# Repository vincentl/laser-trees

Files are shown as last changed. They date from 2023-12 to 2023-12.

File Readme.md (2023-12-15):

# Two Part Laser Cut Christmas Tree with 3D Printed Star

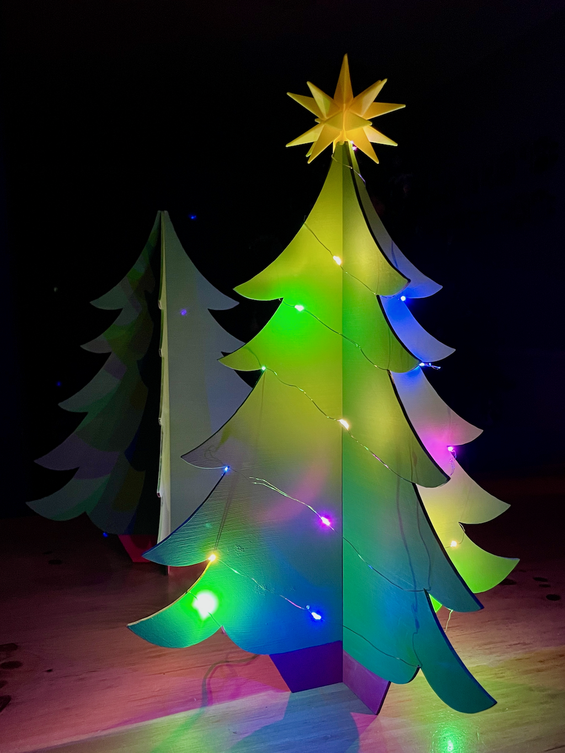
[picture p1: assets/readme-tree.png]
Image of two intersecting Christmas tree profiles that form a 3D tree


This project contains SVG outlines for laser cutting 2-part Christmas trees
from 3mm plywood and 3D printing stars for larger trees.

## SVG files for Laser Cutting Trees

The `trees` directory contains various SVG files that contains paths to cut two
Christmas tree silhouettes from 3mm plywood. The two parts interlock to form a 
self-supporting, 3D Christmas tree.
- `2-part-tree-50mm.svg`, `2-part-tree-75mm.svg`, and `2-part-tree-100mm.svg`, contain paths for both parts and the dimension indicates the height of the tree
- `2-part-tree-400mm-square-bottom.svg` and `2-part-tree-400mm-square-top.svg` each contain a path for one part that fits on a 400mm square plywood sheet that together produce a 445mm tall tree.
- `2-part-tree-template.svg` contains two paths that must be aligned and combined to form a tree of any desired height.
  - Scale the tree path to the desired height and lock the width to scale proportional to the height
  - Scale the rectangular cut path to **half** the desired height **independent** of the width
  - Adjust the width of the rectangular cut to match the material thickness plus a tolerance
  - Repeat the following steps twice to create the two different interlocking parts
    - Align the rectangle to top of the tree (and then the bottom for the other part)
    - Select both parts and combine with the "Difference" operator

## 3D Stars

The `stars` directory contains two 3D models for tree topper stars. Both models
have three types of parts:
- `core` is polyhedron center for that star and the other parts are glued to the core
- spikes that form the majority of the star
- `clip` is a truncated spike designed to clip onto the top of the tree. The clips are designed for 3mm plywood and are sized for a 445mm tall tree.

The parts are designed in [OpenSCAD](https://openscad.org/) language. OpenSCAD
renders 3D models and the rendered models for each part is also included in
this project for convenience.

### Stellated Dodecahedron Star

The [Great Stellated Dodecahedron](https://en.wikipedia.org/wiki/Great_stellated_dodecahedron)
looks like an icosahedron with 20 spikes. In this 3D model, one spike is 
modified to anchor the star to the tree.
- Print one `core` and one `clip`. Print these with some amount of infill for strength.
- Print 19 `spike` parts. These can be printed in "vase" mode with zero infill.
- Use glue appropriate for the 3D printing material and adhere each part to the core.

### Moravian Star

A [Moravian Star](https://en.wikipedia.org/wiki/Moravian_star) is a rhombicuboctahedron
polyhedron with 26 spikes (18 have a square base and 8 have a triangular base). In this 3D
model, one spike is modified to anchor the start to the tree.
- Print one `core` and one `clip`. Print these with some amount of infill for strength.
- Print 17 `square` spikes (the clip forms the 18th square spike) and 8 `triangle` spikes.
- Use glue appropriate for the 3D printing material and adhere each part to the core.

# License

Two Part Laser Cut Christmas Tree with 3D Printed Star © 2023 by Vincent
Lucarelli is licensed under [CC BY-SA 4.0](http://creativecommons.org/licenses/by-sa/4.0/).

> `trees/2-part-tree-template-TruTone-source.pdf` is not covered by this
> license. The file was obtained in 2023 from the publicly available page
> https://tru-tone.com/pages/2-part-christmas-tree-diy-decoration. The file did
> not include licensing information.

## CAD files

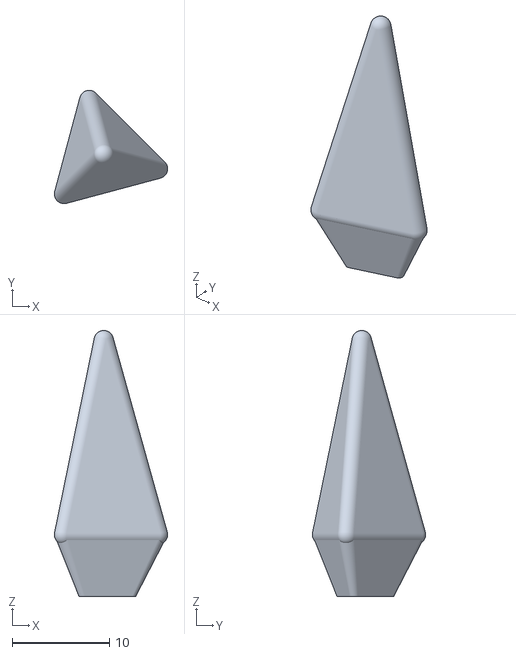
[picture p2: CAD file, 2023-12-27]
stars/moravian/stl/triangle.stl
11.7 x 11.7 x 27.4

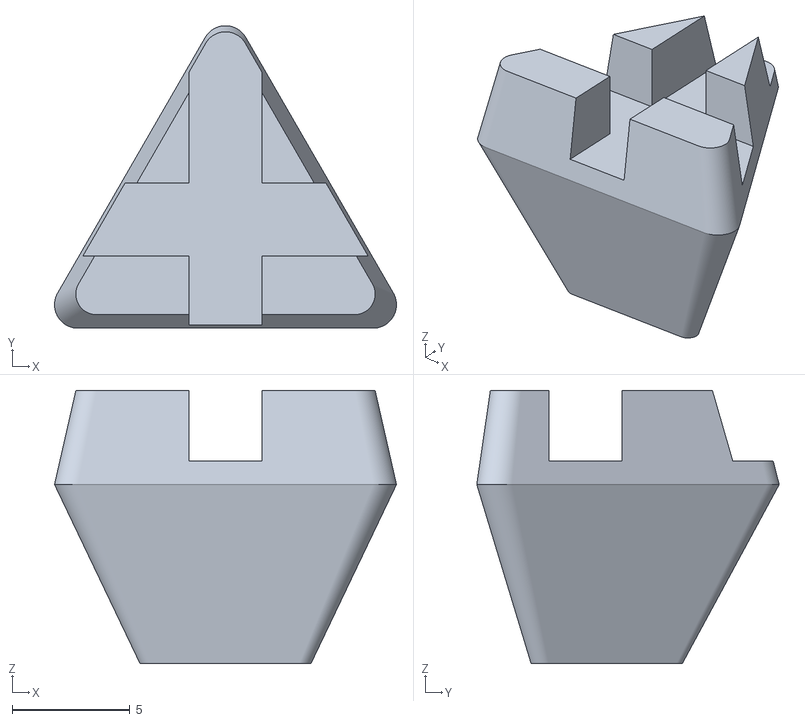
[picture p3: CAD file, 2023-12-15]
stars/stellated-dodecahedron/stl/clip.stl
14.5 x 12.9 x 11.6

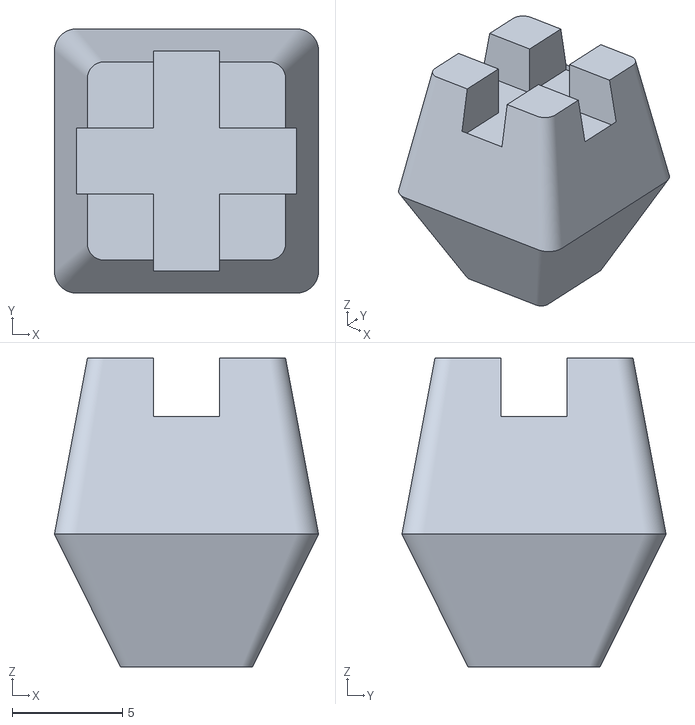
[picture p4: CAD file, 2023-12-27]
stars/moravian/stl/clip.stl
12.0 x 12.0 x 14.0

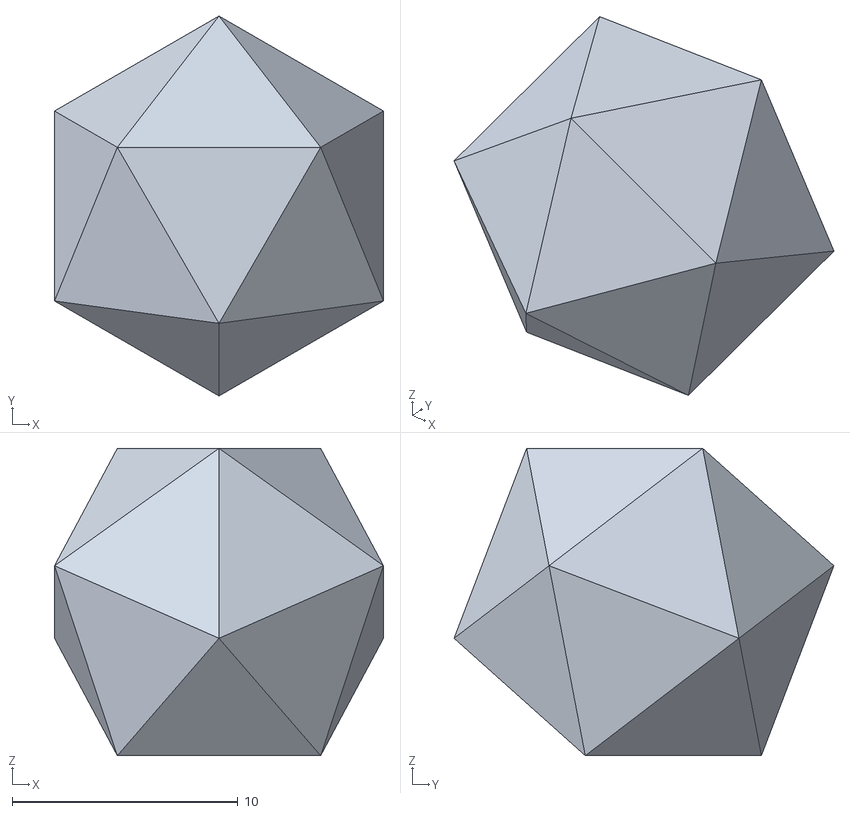
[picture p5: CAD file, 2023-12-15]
stars/stellated-dodecahedron/stl/core.stl
14.6 x 16.8 x 13.6

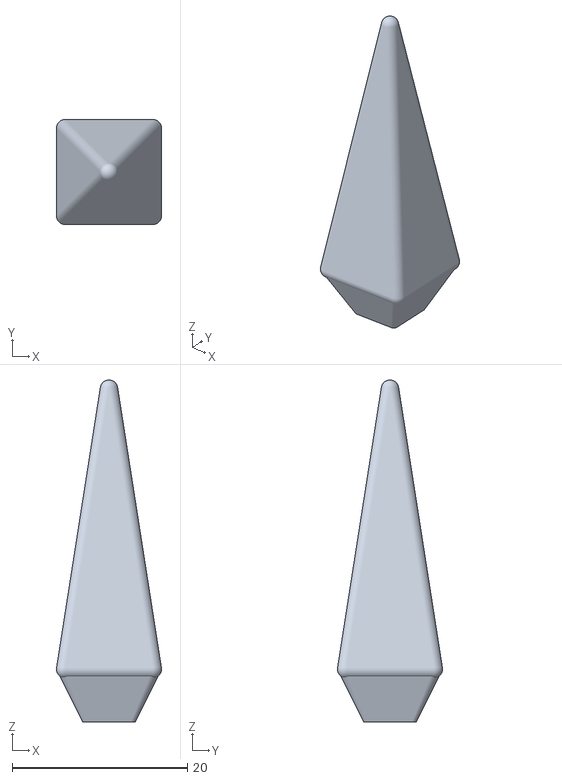
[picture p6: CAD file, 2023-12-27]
stars/moravian/stl/square.stl
12.0 x 12.0 x 39.0

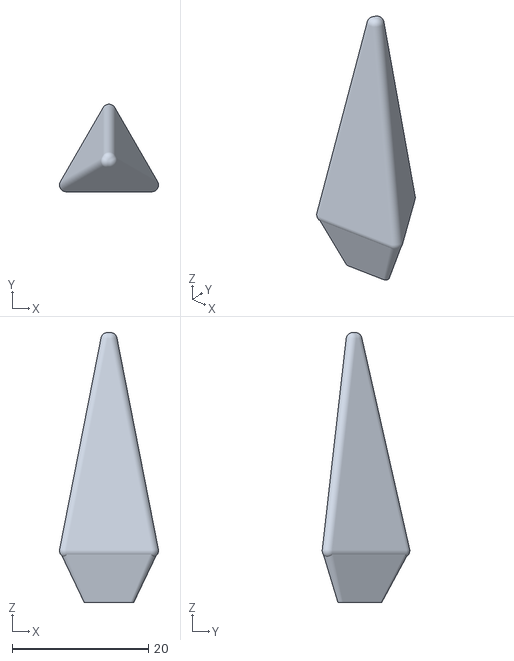
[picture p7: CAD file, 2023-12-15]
stars/stellated-dodecahedron/stl/spike.stl
14.5 x 12.9 x 39.6

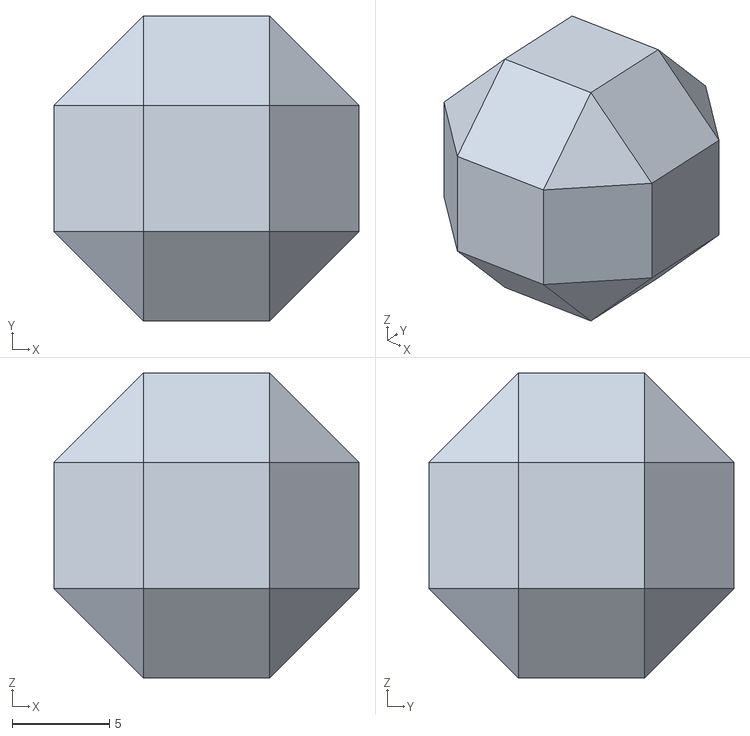
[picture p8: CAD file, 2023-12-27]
stars/moravian/stl/core.stl
15.7 x 15.7 x 15.7

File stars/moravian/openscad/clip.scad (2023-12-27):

m =  1;                 // minkowski radius
h = 32;                 // Height of spike
e =  5;                 // 1/2 Edge length of a spike
c = e*(1 + sqrt(2));    // Largest coordinate for Rhombicuboctahedron
j =  8;                 // Height of clip spike

b = 3;                  // board thickness
w = 2;                  // clip wall
l = 3;                  // clip wall depth

mirror([0,0,1])
  linear_extrude(height=0.5*c,scale=0.5)
    minkowski() {
      polygon([[e,e],[e,-e],[-e,-e],[-e,e]]);
      circle(r = m, $fn=180);
    }

difference(){
  linear_extrude(height=j,scale=1 - j/h)
    minkowski() {
      polygon([[e,e],[e,-e],[-e,-e],[-e,e]]);
      circle(r = m, $fn=180);
    }
    
  translate([0,0,j-l/2]) {
    cube([2*e,b,l], center=true);
    cube([b,2*e,l], center=true);
  }
}

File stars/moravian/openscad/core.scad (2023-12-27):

m =  1;                 // minkowski radius
h = 32;                 // Height of spike
e =  5;                 // 1/2 Edge length of a spike
c = e*(1 + sqrt(2));    // Largest coordinate for Rhombicuboctahedron

E = e + m + 0.5;        // edge + minkowski + tolerance
C = E*(1 + sqrt(2));    // c for expanded Rhombicuboctahedron

hull() 
{
  cube([E, E, C], center=true);
  cube([E, C, E], center=true);
  cube([C, E, E], center=true);
}

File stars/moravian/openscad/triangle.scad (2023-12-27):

m =  1;                 // minkowski radius
h = 20;                 // Height of spike
e =  5;                 // 1/2 Edge length of a spike
c = e*(1 + sqrt(2));    // Largest coordinate for Rhombicuboctahedron

// Compute v - the vector perpendicular to the triangle face
uv = cross([e-c,0,c-e], [0,e-c,c-e]);
v = uv * 1/norm(uv);

// Rotate v to the z-axis
// a is the vector to rotate around
z = [0,0,1];
ua = cross(v,z);
a = ua * 1/norm(ua);

// theta is the angle of rotation
theta = acos(v * z);

// Wikipedia Rodrigues' rotation formula
I = [[1,0,0],[0,1,0],[0,0,1]];
K = [[0,-a[2],a[1]],[a[2],0,-a[0]],[-a[1],a[0],0]];
R = I + sin(theta)*K + (1-cos(theta))*K*K;
M = [[R[0][0], R[0][1], R[0][2], 0], [R[1][0], R[1][1], R[1][2], 0], [R[2][0], R[2][1], R[2][2]]];

// Extract face from rotation matrix
echo(R*[e,e,c]);
echo(R*[e,c,e]);
echo(R*[c,e,e]);

A = R*[e,e,c];
B = R*[e,c,e];
C = R*[c,e,e];

face = [[A[0],A[1]],[B[0],B[1]],[C[0],C[1]]];

mirror([0,0,1])
  linear_extrude(height=0.5*A[2],scale=0.5)
    minkowski() {
      polygon(face);
      circle(r = m, $fn=180);
    }
    
minkowski(){
  linear_extrude(height=h,scale=0) {
    polygon(face);
  }
  sphere(r=m,$fn=180);
}

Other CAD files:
stars/moravian/openscad/square.scad
stars/stellated-dodecahedron/openscad/clip.scad
stars/stellated-dodecahedron/openscad/core.scad
stars/stellated-dodecahedron/openscad/spike.scad

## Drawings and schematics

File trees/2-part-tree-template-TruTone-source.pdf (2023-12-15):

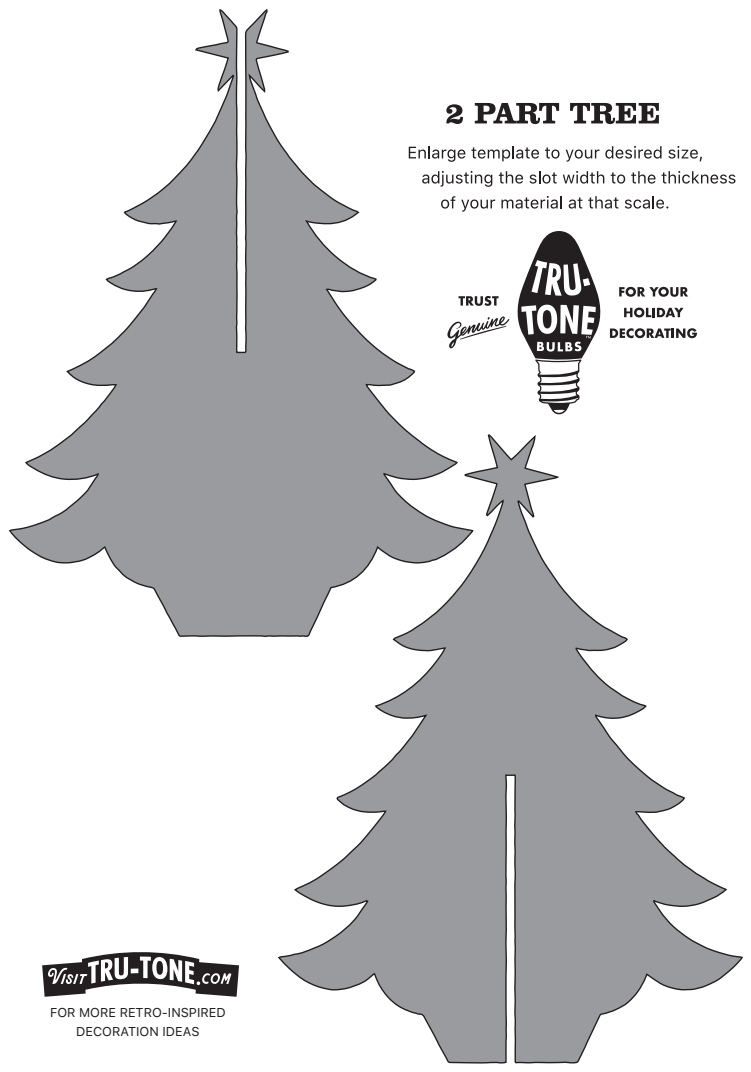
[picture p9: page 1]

FOR MORE RETRO-INSPIRED
DECORATION IDEAS
